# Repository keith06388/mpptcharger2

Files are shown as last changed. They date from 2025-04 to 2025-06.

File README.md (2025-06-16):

# Backpacking MPPT Solar Charger Version 2
Solar charger designed to charge lithium ion cells directly, bypassing USB charging circuit.  

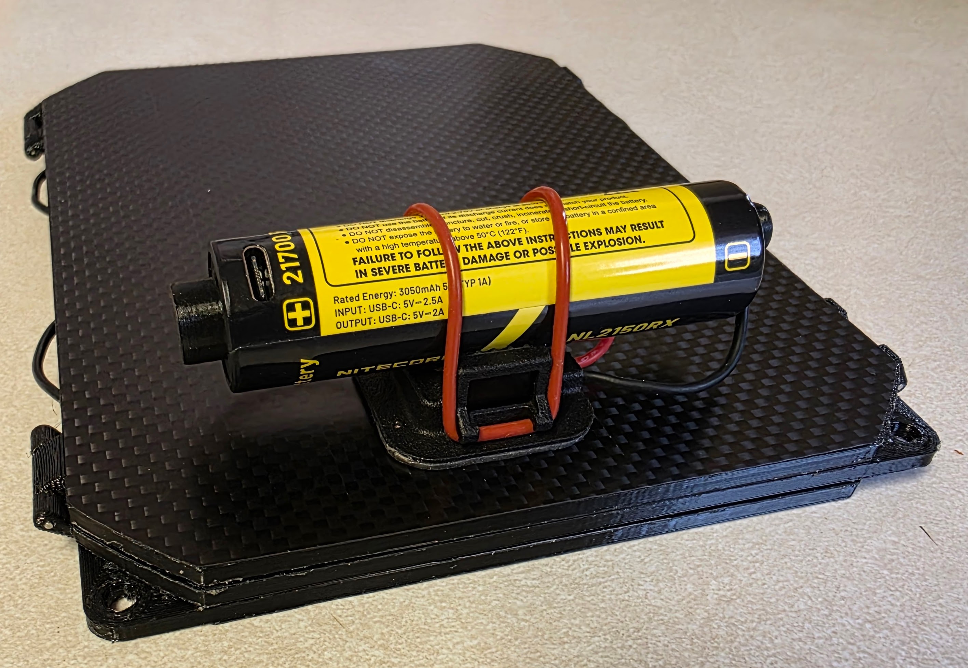
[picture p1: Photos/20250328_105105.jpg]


## Features

Advantages of this design:
* Very high efficiency buck converter
* Full MPPT tracking using BQ25622e chip (upgraded from BQ24650)
* Integrated power meter, source voltage, battery voltage, and battery charge indicator
* Passthrough charging to charge device and battery simultaneously
* Integrated battery attachment for simple attachment to pack while hiking
* Automatically adjustable to different panel voltages (3.8-18V)
* Avoid 2 stage voltage drop to cells for higher total efficiency (solar -> battery vs solar -> USB -> battery)
* Magnetic battery contacts designed to avoid reverse polarity connection
* Compatibility with both Nitecore NL2150RX and Vapcell P2150A
* Easy connection for software updates

## PCB
* Designed with easyeda software
*   Project link: https://u.easyeda.com/keith06388/solar-mppt-charger-v4
* PCBA assembled by JLCPCB
* Primary components:
  * BQ25622e - mppt solar battery charging chip
  * ATTINY1616 - arduino compatible microcontroller
  * 3.8-18V input voltage range
  * Up to 3.0A charging current
  * 10hz MMPT update rate
  * 40mV MPPT voltage resolution
  * Up to 95% conversion efficiency
* Connections:
  * S+/S- Solar input
  * B+/B- Battery output
  * UPDI Programming port
  * LCD 0.42" SSD1306 display

## 3D Printed Parts
* Housing (printed with JLCPCB in nylon)
* Positive and negative battery contacts (printed with PETG)
*   Printing of the positive contact was paused to allow installation of the magnet into the housing before lip printed

## Purchased Parts
* Magnets from K&J (D42AH and D62SH)
  * High temperature magnets to allow soldering without demagnetization
* Sn42Bi58 solder for attaching wire to magnets at low temperature
* 20AWG silicone flexible wire (red and black)
* 0.49" SSD1306 OLED
* 28.2mmx33mmx2.4mm 50D silicone o-ring
* 1mm rubber grip tape to prevent battery from sliding
* Short piece of flat wire (used for programming after assembly)
* Custom solar panel using sunpower solar cells

* ## Custom Panel Parts
* Knurl pins (1.2mm x 20mm) https://www.amazon.com/dp/B0BC1VN8J9
* Solar cells sunpower Gen 3 (small) or Gen 5 (large)
  * Small cells can be ordered cut into 3 sections, but I haven't found a source for cut large cell, but they can be cut with a fiber laser or potentially a razor or dremel
  * https://www.aliexpress.us/item/3256801658021801.html
  * https://www.aliexpress.us/item/3256805555889765.html
* Laminator sheets (5mil works well, but 3mil should work too)
* 0.2mm carbon fiber sheet for back side.  This could be substituted with plastic sheet to cut cost.  https://www.aliexpress.us/item/3256805950798977.html
* Pressure sensitive adhesive to attach laminated solar cells and foam/frame and also rear carbon fiber sheet to foam/frame
* Solar busbar and flux (I used 2x 1mm x 0.2mm busbars for each connection)
* 3mm architectural foam
* Magnets from K&J (2x B631-N52 for magnetic closure)
* PETG filament for frame.  I printed the frame with 0.8mm lateral walls and approximately 0.6mm top and bottom thickness with 20% grid infill.  I made the hinge areas 100% infill using a box in prusa slicer
  * Large panel CAD (approx 13W): https://a360.co/3wPAMOi
  * Small panel CAD (approx 10W): https://a360.co/4cJ9c5N

## Assembly
Testing of the performance was completed by building a custom panel, however, this module could be used to replace the charge module on a panel such as the lixada solar panel available on amazon

Installation steps for Lixada panel:
* Carefully remove solar to USB module from panel using a razor blade to cut adhesive under module and a soldering iron to desolder leads from panel
* Scrape any remaining adhesive off and clean with alcohol
* Solder new assembled pcb with housing and leads to panel
* Use epoxy to glue housing to panel

## Software Install or Upgrade
* UPDI programming can be performed with a cheap CH340 board and a Schottky diode installed across the TX and RX pins (with diode facing TX pin)
* Programming requires a power supply (either benchtop or solar) and UPDI programmer with connections to ground and the UPDI programming pin
* Before programming for the first time, the "megaTinyCore" board needs to be installed in Arduino and the bootloader should be burned (see image below for bootloader and programming settings, the COM port will need to be selected for your programmer port)

  

* Once the bootloader is burned, the software can be installed.  The software is found in this repository and the following libraries need to be installed:
  * Tiny4KOLED - installed through Arduino library manager
  * BQ25622 - installed manually by downloading the .zip archive from github and installing by Sketch -> Include Library -> Add .Zip Library  The library is located here: https://github.com/keith06388/PMIC_BQ25622
  * With the programmer correctly connected (GND to battery or solar ground, and UPDI in contact with UPDI pin, the software can be installed using Sketch -> Upload using programmer
* Latest software notes:
  * Resolved issue with charger locking up after low voltage shutdown (but not completely dropped to 0V).  Screen now shuts off after dropping below 4.5V and turns back on above 5.0V
  * Slight increase in efficiency by forcing Mosfet 1 and 4 always in low resistance state
  * Resolved issue for OLED display when power is above 10W

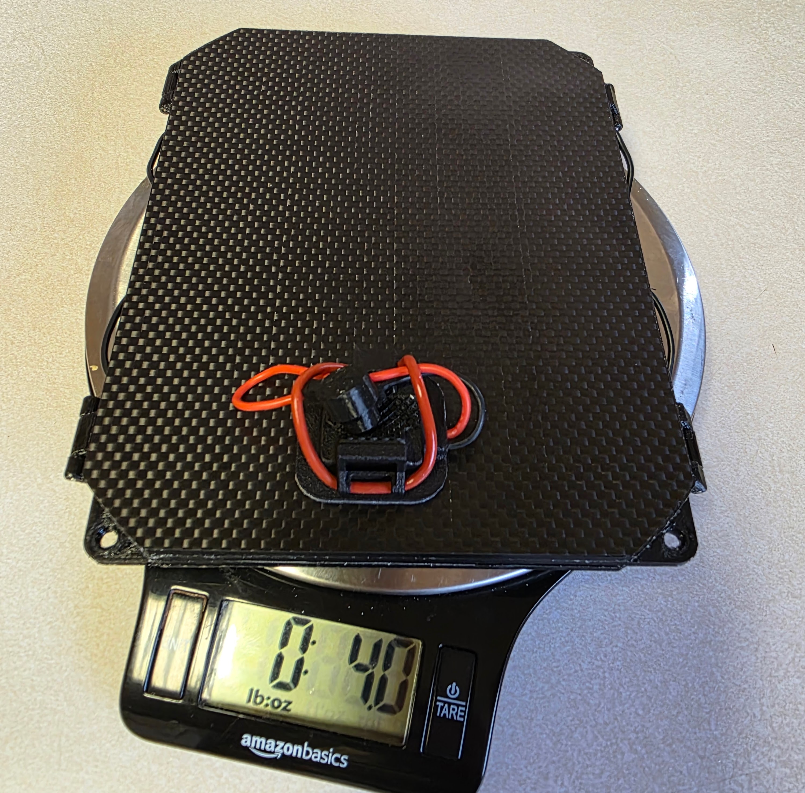
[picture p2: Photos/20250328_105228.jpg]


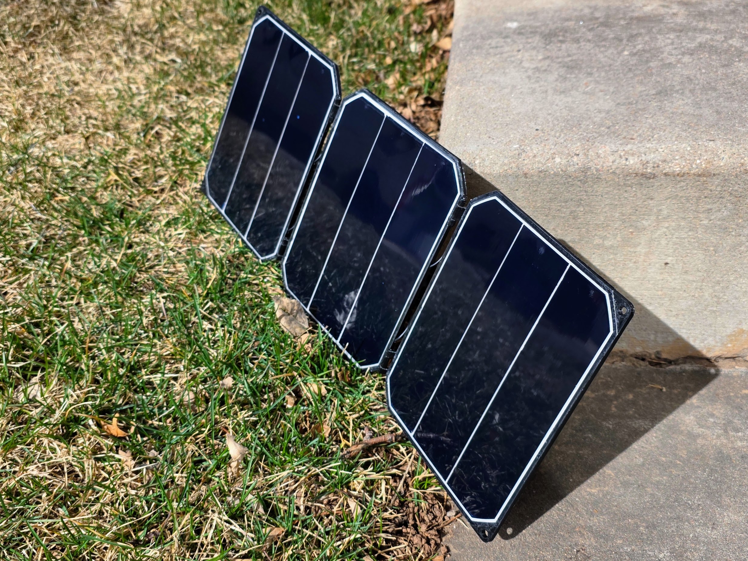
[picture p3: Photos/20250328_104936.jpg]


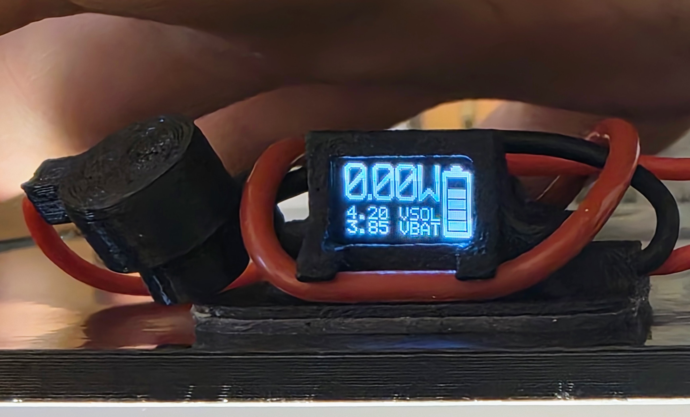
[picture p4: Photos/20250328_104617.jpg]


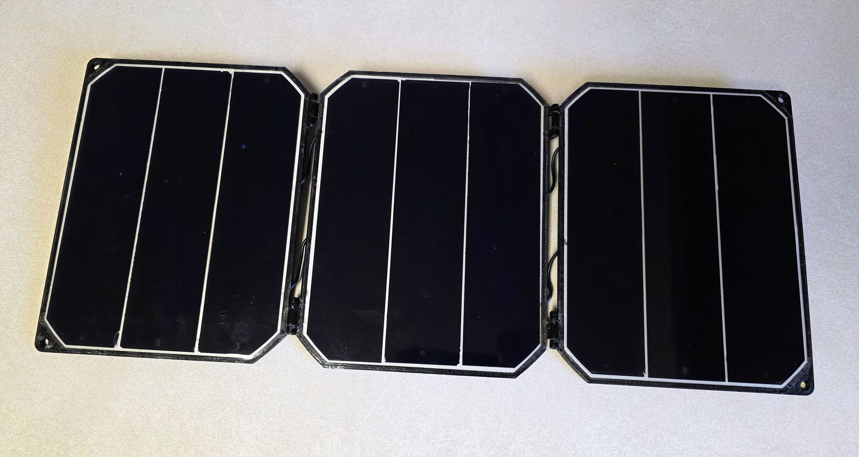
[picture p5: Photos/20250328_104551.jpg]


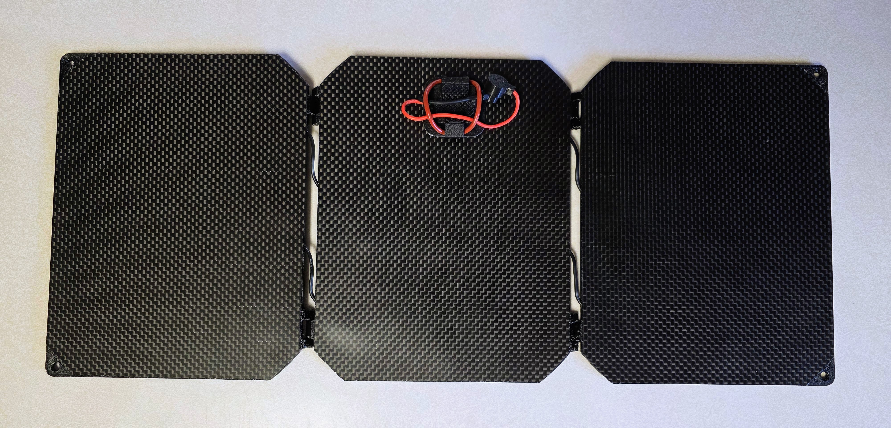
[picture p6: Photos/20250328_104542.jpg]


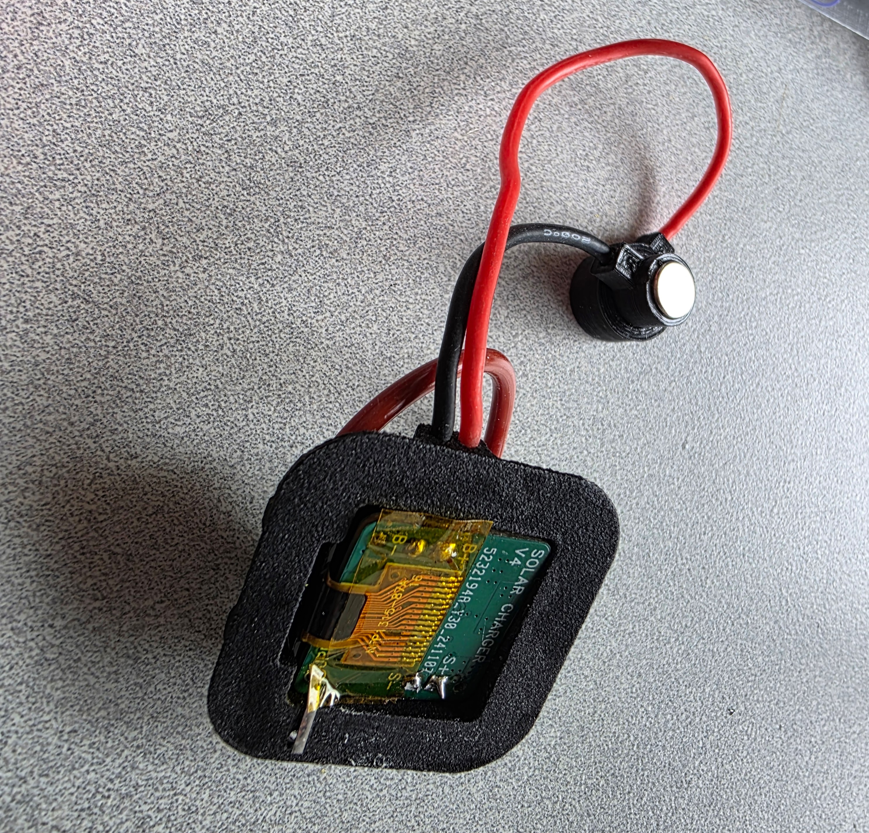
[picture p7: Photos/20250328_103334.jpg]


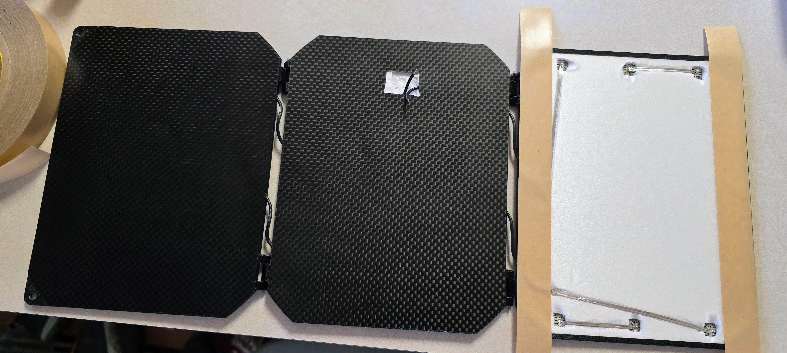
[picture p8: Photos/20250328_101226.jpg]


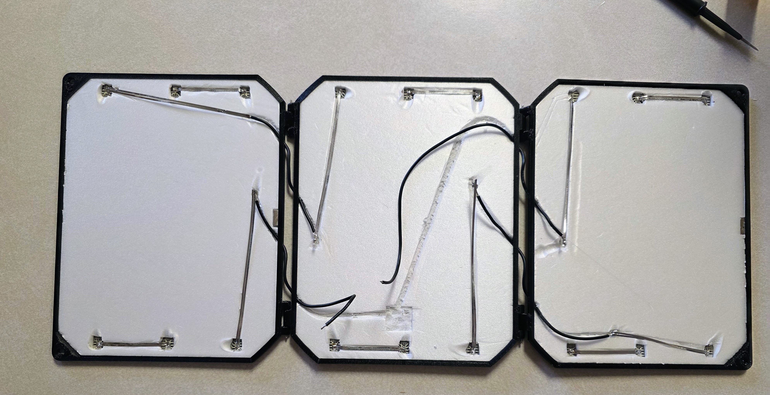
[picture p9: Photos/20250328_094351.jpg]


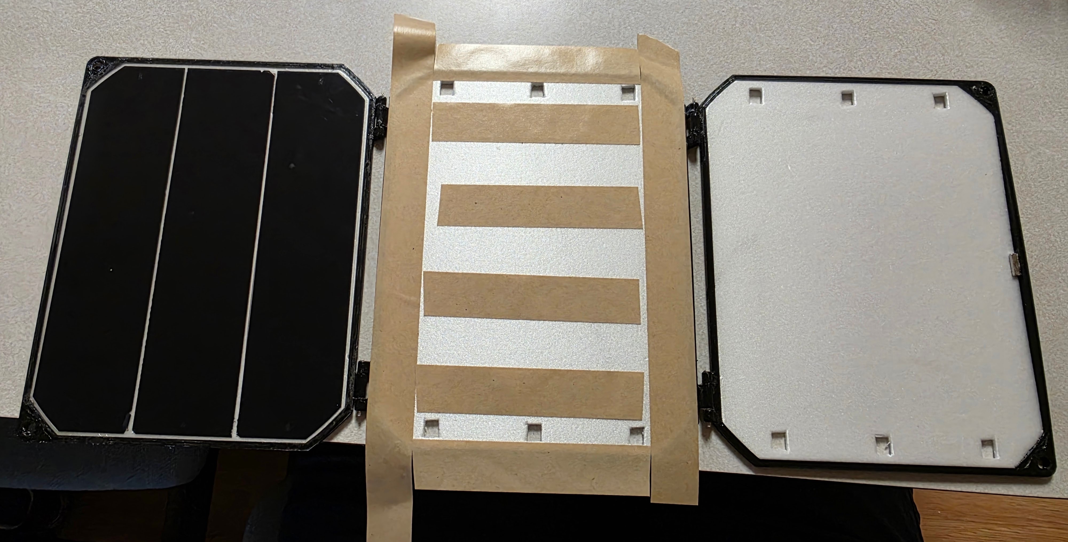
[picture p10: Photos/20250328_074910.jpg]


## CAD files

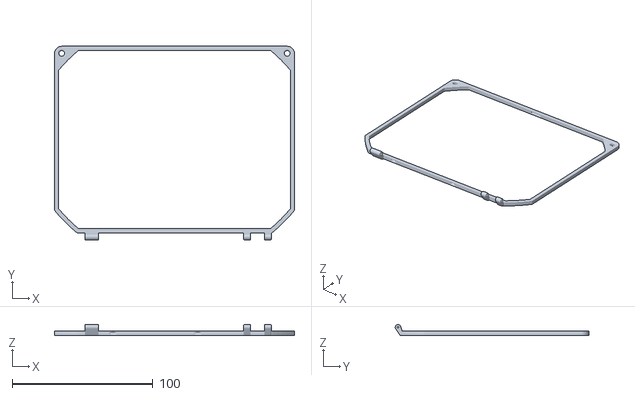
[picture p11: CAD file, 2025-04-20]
3D Printed Parts/Large_left_frame.stl
170.7 x 137.7 x 7.85

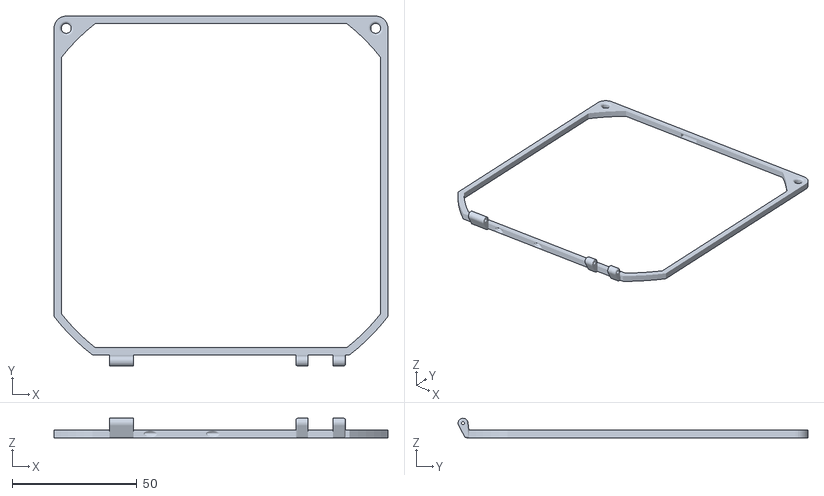
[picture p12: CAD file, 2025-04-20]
3D Printed Parts/Small_left_frame.stl
134.0 x 140.3 x 7.85

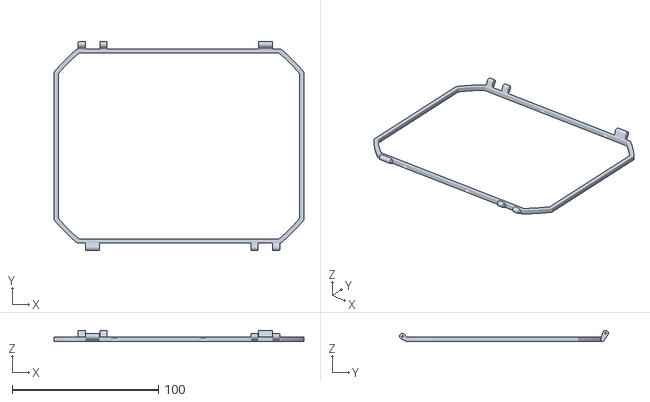
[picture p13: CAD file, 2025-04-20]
3D Printed Parts/Large_middle_frame.stl
170.7 x 142.7 x 7.85

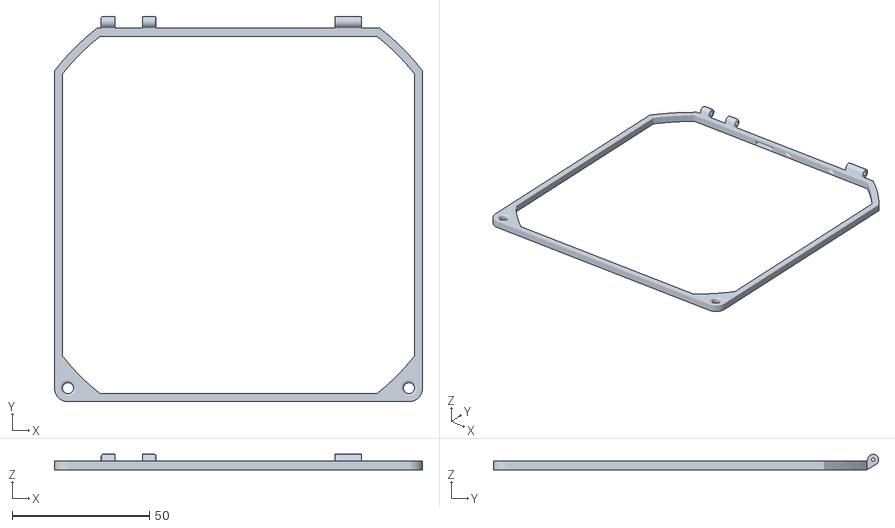
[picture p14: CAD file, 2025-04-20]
3D Printed Parts/Small_right_frame.stl
134.0 x 140.3 x 5.70

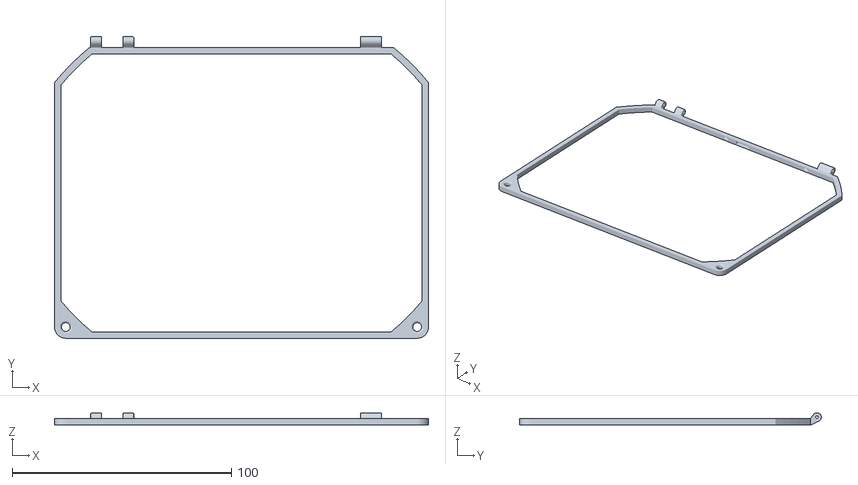
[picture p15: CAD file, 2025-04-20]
3D Printed Parts/Large_right_frame.stl
170.7 x 137.7 x 5.68

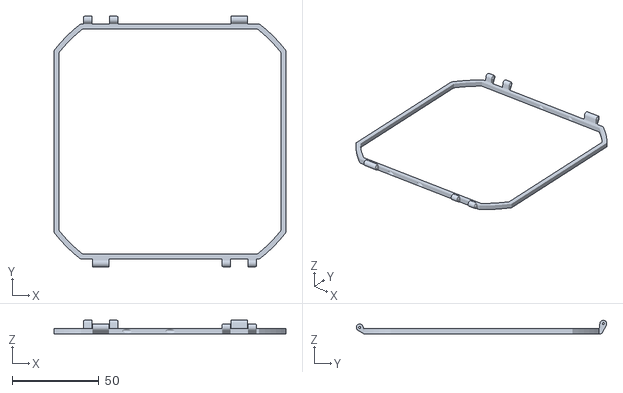
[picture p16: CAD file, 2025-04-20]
3D Printed Parts/Small_middle_frame.stl
134.0 x 144.7 x 7.85

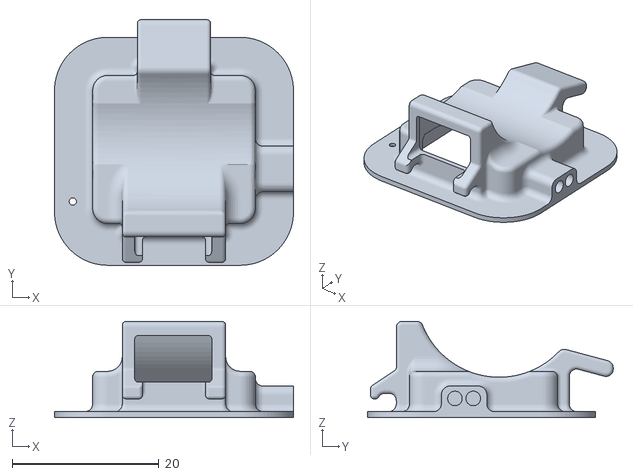
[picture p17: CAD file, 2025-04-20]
3D Printed Parts/Cover.stl
32.6 x 33.5 x 13.1

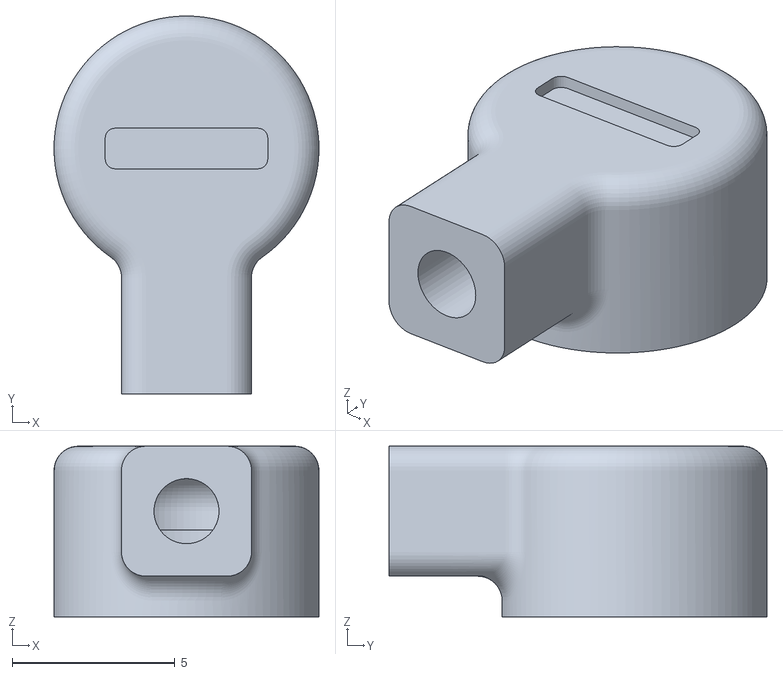
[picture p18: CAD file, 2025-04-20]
3D Printed Parts/Minus.stl
8.15 x 11.6 x 5.25

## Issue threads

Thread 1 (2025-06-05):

Delayed wake in bright sun after lower light; fully shading the panel will reset

edasmalchi, 2025-06-05:
## Issue

Got a chance to test mine (installed to [Lixada panel](https://www.amazon.com/dp/B06Y655DJD)) on a 4 hour day hike last weekend. Sunny day but the trail passed through a few shaded groves. The panel was tied to the top of my backpack, and yielded about 2W in direct sun (angled daypack, can get closer to 3W with the panel on a flatter surface).

Several times when transitioning from those shaded areas back into full sun, I checked the panel and the display was blank.

I eventually realized that if I covered the panel with my body or by flipping it upside down, then flipped it back up it would wake immediately.

So there seems to be some state it enters when power is too low to charge the battery and the display sleeps, but a small amount of power is still available from the panel, and from this state it may not readily recover when bright light returns. If there is zero/minimal power, that does seem to prompt an immediate reset and wake on the next exposure to light.

I was able to replicate at home, see photo and csv for my test setup and some data. In two cases it eventually recovered after about 20 minutes in the brighter location.

[sleep_testing.csv](https://github.com/user-attachments/files/20600226/sleep_testing.csv)

## Theories

I've been reading the BQ25622E datasheet and the code but I don't have a full understanding yet. Noticed the ATTINY is powered via the REGN (LDO) output from the BQ25622E and not SYS. Assuming that's in order to not drain the battery running the ATTINY and the display when no solar power is available.

Given that I'm curious about states where REGN is inactive, such as part of the power-up sequence on page 19 of the dataset (section 8.3). Also "8.3.4.2 Dynamic Power Management" on page 20, which doesn't specifically mention REGN inactivation but does mention a switch to battery/supplement mode when VBUS is below VINDPM.

I'm also curious how exactly fully shading the panel promptly resets it, perhaps by ensuring the whole power-on reset sequence occurs on the next exposure to sufficient light.

## Practical Considerations

This issue can be somewhat mitigated (by checking the panel when re-entering bright light and flipping if required), but some energy loss could still occur. It's likely less of an issue for more powerful panels, which would be less likely to drop into this low-but-not-zero power range in the first place.

Planning to experiment with the software a bit, perhaps starting with the watchdog timer to see if that could possibly make any difference. Not planning to experiment with the hardware at this time, but may if/when I decide to order more boards.

Even if I don't find a solution I'll keep using the panel, thanks again for all your work!

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

keith06388, 2025-06-09:
Thanks for bringing this up.  I had this issue with my last version of the charger, but I thought it was solved this time since I hadn't encountered it.  I think I just avoided it with a 13w panel, so it doesn't drop too low unless it gets quite dark.

I have brown out detection turned on for the attiny chip, but I think maybe the bq chip is dropping out without the attiny triggering brown out.  I think maybe some basic error handling and reinitialization may fix the problem.

I'm planning to carry the panel on a thru hike this summer, so it would be great to find a fix before I leave in a couple weeks.  I'll start digging back into it later this week

edasmalchi, 2025-06-16:
Thanks so much! Successfully flashed the new software.

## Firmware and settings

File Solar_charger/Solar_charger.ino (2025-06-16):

#include <Tiny4kOLED.h>
#include "spleen.h"
#include "batt.h"
#include <PMIC_BQ25622.h>


uint8_t i = 0;
uint8_t lvl = 0;
uint8_t bar = 0;
uint8_t n = 0;
uint8_t m = 0;
uint16_t vindpm = 5000;
uint16_t vs = 0;
uint16_t vb = 0;
uint16_t v0 = 0;
int16_t ic = 0;
uint16_t p = 0;
int dp = 0;
int dv = 0;
uint16_t p0 = 0;
int16_t il = 3200;
bool oledon = 0;
PMIC_BQ25622 bq25622;


void setup() {
  //Turn off screen
  digitalWrite(PIN_PA4,LOW);
  delay(50);
  //Initialize I2C
  Wire.begin();
  Wire.setClock(100000);
  bq25622.begin();
  //Turn on screen and initialize
  digitalWrite(PIN_PA4,HIGH);
  oled.begin(72, 40, sizeof(tiny4koled_init_72x40br), tiny4koled_init_72x40br);
  oled.off();
  oledon = 0;
  oled.clear();
  //Initialize BQ25622e
  bq25622.reset(); //reset all registers to default
  bq25622.setWATCHDOG(0);
  bq25622.setEN_EXTLIM(false); //disable hardware ilim pin
  bq25622.setCONV_RATE(true); //set continous adc 1s read
  bq25622.setADC_SAMPLE(1); //read adc in one shot (default)
  bq25622.setCONV_START(true); //read adc in one shot (default)
  bq25622.setQ1_FULLON(1); //Q1 low impedance
  bq25622.setQ4_FULLON(1); //Q4 low impedance
  bq25622.setTS_IGNORE(true);
  bq25622.setVPMID_ADC_DIS(true);
  bq25622.setTDIE_ADC_DIS(true);
  bq25622.setTS_ADC_DIS(true);
  bq25622.setVSYS_ADC_DIS(true);
  bq25622.setIBUS_ADC_DIS(true);
  bq25622.setVBUS_ADC_DIS(false);
  bq25622.setVBAT_ADC_DIS(false);
  bq25622.setIBAT_ADC_DIS(false);
  bq25622.setITERM(100);
  bq25622.setVREG(4200);
  bq25622.setVINDPM(vindpm);
  bq25622.setCONV_FREQ(2);
  bq25622.setCONV_STRN(3);
  bq25622.setEN_CHG(1);
  bq25622.setICHG(3040);
}

void loop() {
  for (n = 0; n < 4; n++) {
    for (m = 0; m < 4; m++) {
      // Start ADC conversion
      bq25622.setCONV_START(true);
      delay(36);

      // Read voltage & current values
      vs = bq25622.getVBUSV();  
      vb = bq25622.getBATV();
      ic = bq25622.getIBAT();  

      // Turn off OLED if power too low
      if ((vs < 4500) && (oledon == 1)) {
        oled.off();
        oledon = 0;
      }
      else if ((vs >= 5000) && (oledon == 0)) {
        oled.on();
        oledon = 1;
        oled.clear();
      }

      // Compute power (P = V * I)
      p = vb * (ic / 1000.0);  // Convert mA to A
      dp = p - p0;
      p0 = p;
      dv = vindpm - v0;
      v0 = vindpm;

      // Apply Perturb and Observe MPPT algorithm
      if (abs(dp) > 100 || abs(dv) > 100) {  
        if (dp > 0) {
          vindpm += (dv < 0) ? -40 : 40;
          // if (il < 3200) {
          //   il += 100;
          //   bq25622.setIINDPM(il);
          // } 
        } else {
          vindpm += (dv < 0) ? 40 : -40;
          // if (il < 3200) {
          //   il += 100;
          //   bq25622.setIINDPM(il);
          // } 
        }
      } else {
        if (p >= 100 && dv > 0) {
          vindpm += 40;
          // if (il < 3200) {
          //   il += 100;
          //   bq25622.setIINDPM(il);
          // } 
        } else if (p < 100) {
          vindpm = 5000;
          // il = 100;
          // bq25622.setIINDPM(il);
        }
      }

      // Ensure vindpm stays within safe limits
      if (vindpm < 5000) vindpm = 5000;
      //if (vindpm > vs - 50) vindpm = vs - 50;

      // Apply the new voltage limit
      if (vindpm != v0) {
        bq25622.setVINDPM(vindpm);
        delay(30);
      }
    }

    // Update battery charge level display
    int level = meter(vb, ic);
    if (ic > 20) bar = level - i;
    else if (ic <= 0 && vb < 3300) bar = 0;
    else bar = level;

    // Update OLED display
    updateoled(p, bar, vs, vb);

    m = 0;
  }
  n = 0;
  i = (i == 0) ? 1 : 0;  // Toggle `i` between 0 and 1 to flash charging icon, while charging
}

//Print output to screen
void updateoled(uint16_t u, uint8_t x, uint16_t y, uint16_t z){
  oled.setFont(FONTspleen);
  oled.setCursor(0,0); 
  //For > 10W, only use 1 decimal place to fit screen
  if (p >= 10000) {
    oled.print(u/1000.0,1);
  }
  else {
    oled.print(u/1000.0,2);
  }
  oled.setCursor(42,0); 
  oled.print("/");
  oled.setCursor(56,0);
  oled.setFont(FONTbatt);
  oled.print(x);
  oled.setFont(FONT6X8);
  oled.setCursor(0,3);
  oled.print(y/1000.0,2);
  oled.print(" VSOL");
  oled.setCursor(0,4);
  oled.print(z/1000.0,2);
  oled.print(" VBAT");
}


//Approximate power bar calibrations for Vapcell p2150a cell
int meter(float v, float a){
  int lvl;
  if (a>2000){
    if (v<3600) lvl = 1;
    else if (v<3830) lvl = 2;
    else if (v<4050) lvl = 3;
    else if (v<4190) lvl = 4;
    else lvl = 5;
  }
  else if (a>1000){
    if (v<3600) lvl = 1;
    else if (v<3800) lvl = 2;
    else if (v<3950) lvl = 3;
    else if (v<4160) lvl = 4;
    else lvl = 5;
  }
    else if (a>500){
    if (v<3600) lvl = 1;
    else if (v<3720) lvl = 2;
    else if (v<3900) lvl = 3;
    else if (v<4120) lvl = 4;
    else lvl = 5;
  }
    else {
    if (v<3470) lvl = 1;
    else if (v<3630) lvl = 2;
    else if (v<3800) lvl = 3;
    else if (v<4000) lvl = 4;
    else lvl = 5;
  }
  return lvl;

}
